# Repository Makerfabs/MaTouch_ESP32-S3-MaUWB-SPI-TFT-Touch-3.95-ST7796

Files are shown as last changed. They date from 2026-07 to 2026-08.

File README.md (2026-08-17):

# MaTouch ESP32-S3 MaUWB SPI TFT Touch 3.95" ST7796

## Introduction

The MaTouch 3.95 MaUWB is an ESP32-S3 development board featuring a 3.95-inch SPI display driven by the ST7796 controller, with a resolution of 480 x 320. It is equipped with an FT6236 capacitive touch controller, 16 MB Flash, and 8 MB PSRAM, providing responsive display and touch interaction for embedded applications.
The board integrates a MaUWB module for UWB ranging and indoor positioning applications. It also supports battery-powered operation, with an onboard lithium battery connector, charging circuit, battery level monitoring, and charge-status indicators, making it suitable for portable positioning terminals.
With its SPI display design, the board retains multiple GPIOs for secondary development through the expansion interface. It also includes a MicroSD card interface, native USB Type-C port, and USB-to-UART Type-C port for programming, debugging, and data storage.
Combining display, capacitive touch, UWB positioning, battery management, and expandable interfaces in one compact platform, the MaTouch 3.95 MaUWB is suitable for education, indoor positioning projects, embedded product development, and rapid prototyping.

Product Link: [MaTouch ESP32-S3 MaUWB SPI TFT Touch 3.95" ST7796](https://www.makerfabs.com/matouch-esp32-s3-mauwb-spi-tft-touch-3-95-st7796.html)

Wiki Link:  [MaTouch ESP32-S3 MaUWB SPI TFT Touch 3.95" ST7796](https://wiki.makerfabs.com/MaTouch%20ESP32_S3%20MaUWB%20SPI%20TFT%20Touch%203.95%27%27%20ST7796.html)

Example：1.[3.95_UWB_position](https://github.com/Makerfabs/MaTouch_ESP32-S3-MaUWB-SPI-TFT-Touch-3.95-ST7796#395_uwb_position)

## Features

- Controller: ESP32-S3 Chipset, 16MB Flash, 8MB PSRAM
- LCD: 3.95", 480X320 resolution 
- LCD Driver: ST7796
- LCD interface: SPI
- Touch Panel: Capacitive
- Touch Driver: FT6336U
- UWB: [MaUWB Chipset](https://www.makerfabs.com/mauwb-dw3000-chipset-ex-antenna-with-sma.html)
- RF band: CH5 (6489.6MHZ) 
- UWB rate: 850K/6.8M
- Max support: 8 Anchor 64 tags
- USB: 1 * USB_native, 1 *USB-to-UART
- USB-UART Driver: CH340K
- Power Supply: USB Type-C 5.0V(4.0V~5.25V)/ Lipo battery 
- Battery Charger
- Expansion interface: 2*JST1.25mm-4P
- LCD Backlight control: Yes

## Example

### 3.95_UWB_position



For details of this example, please refer to the [Wiki](https://wiki.makerfabs.com/MaTouch%20ESP32_S3%20MaUWB%20SPI%20TFT%20Touch%203.95%27%27%20ST7796.html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) document.

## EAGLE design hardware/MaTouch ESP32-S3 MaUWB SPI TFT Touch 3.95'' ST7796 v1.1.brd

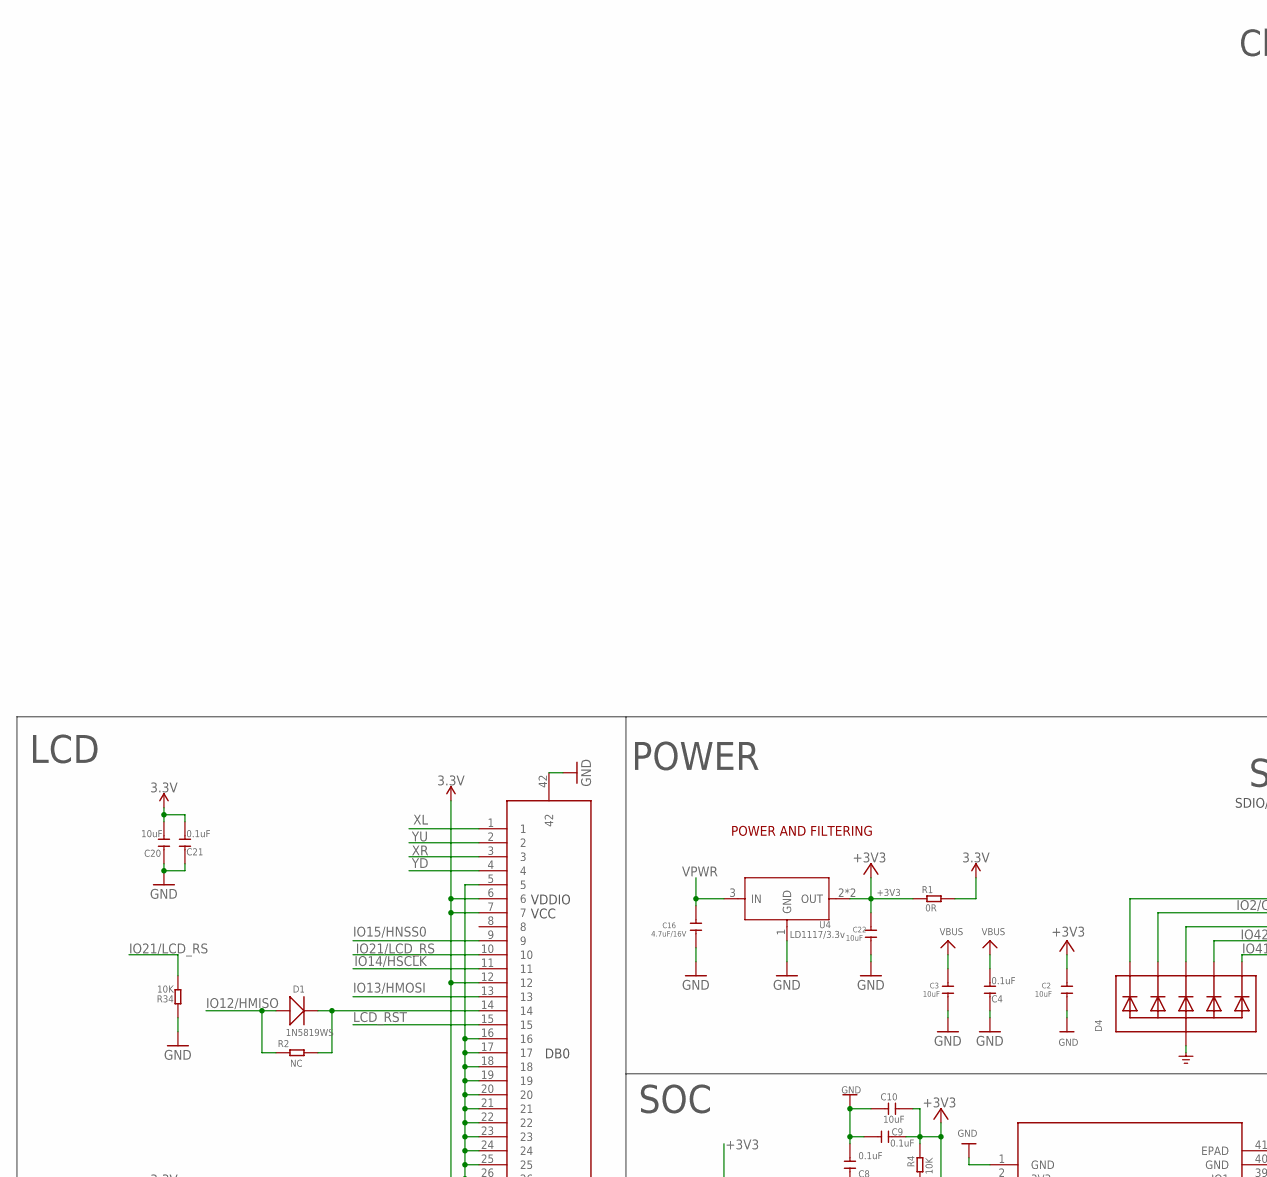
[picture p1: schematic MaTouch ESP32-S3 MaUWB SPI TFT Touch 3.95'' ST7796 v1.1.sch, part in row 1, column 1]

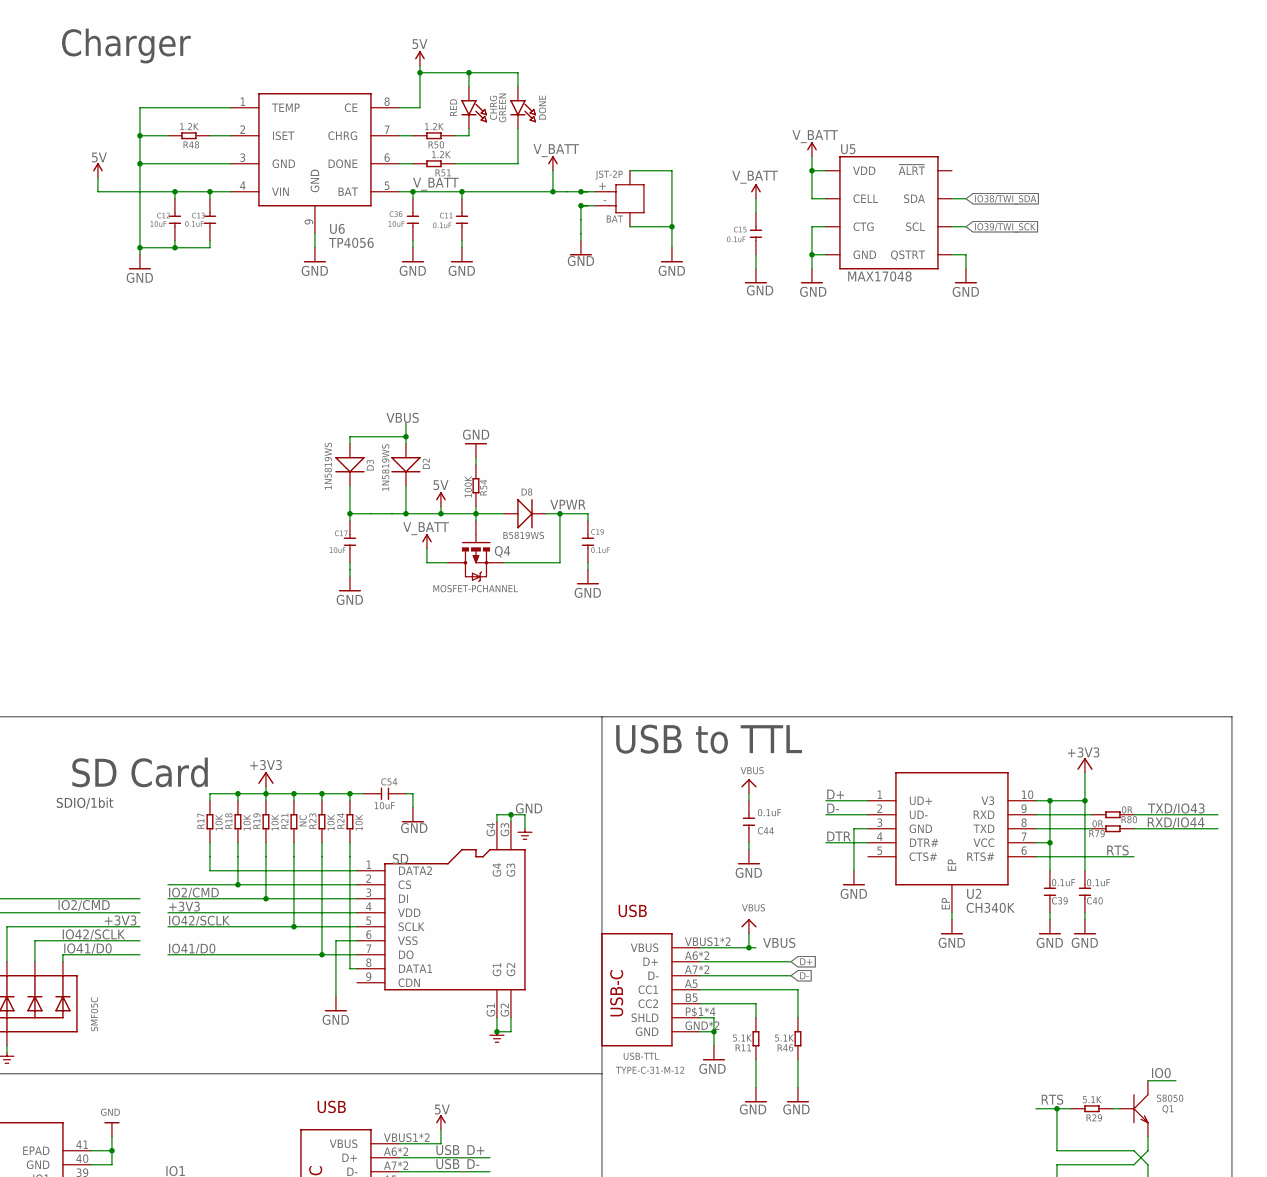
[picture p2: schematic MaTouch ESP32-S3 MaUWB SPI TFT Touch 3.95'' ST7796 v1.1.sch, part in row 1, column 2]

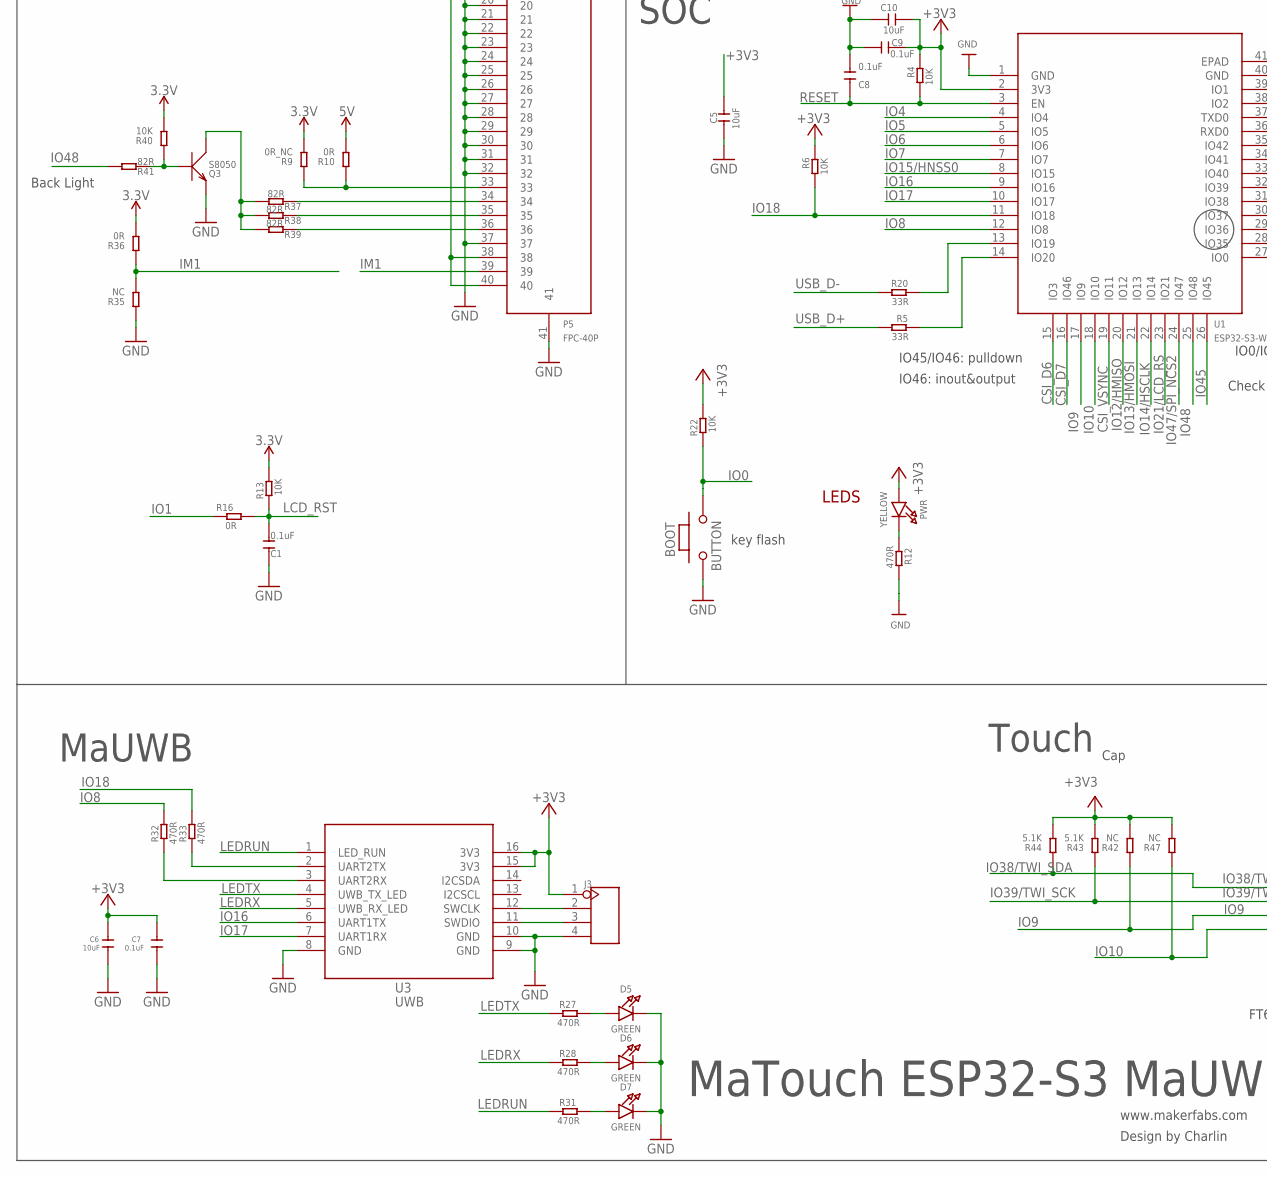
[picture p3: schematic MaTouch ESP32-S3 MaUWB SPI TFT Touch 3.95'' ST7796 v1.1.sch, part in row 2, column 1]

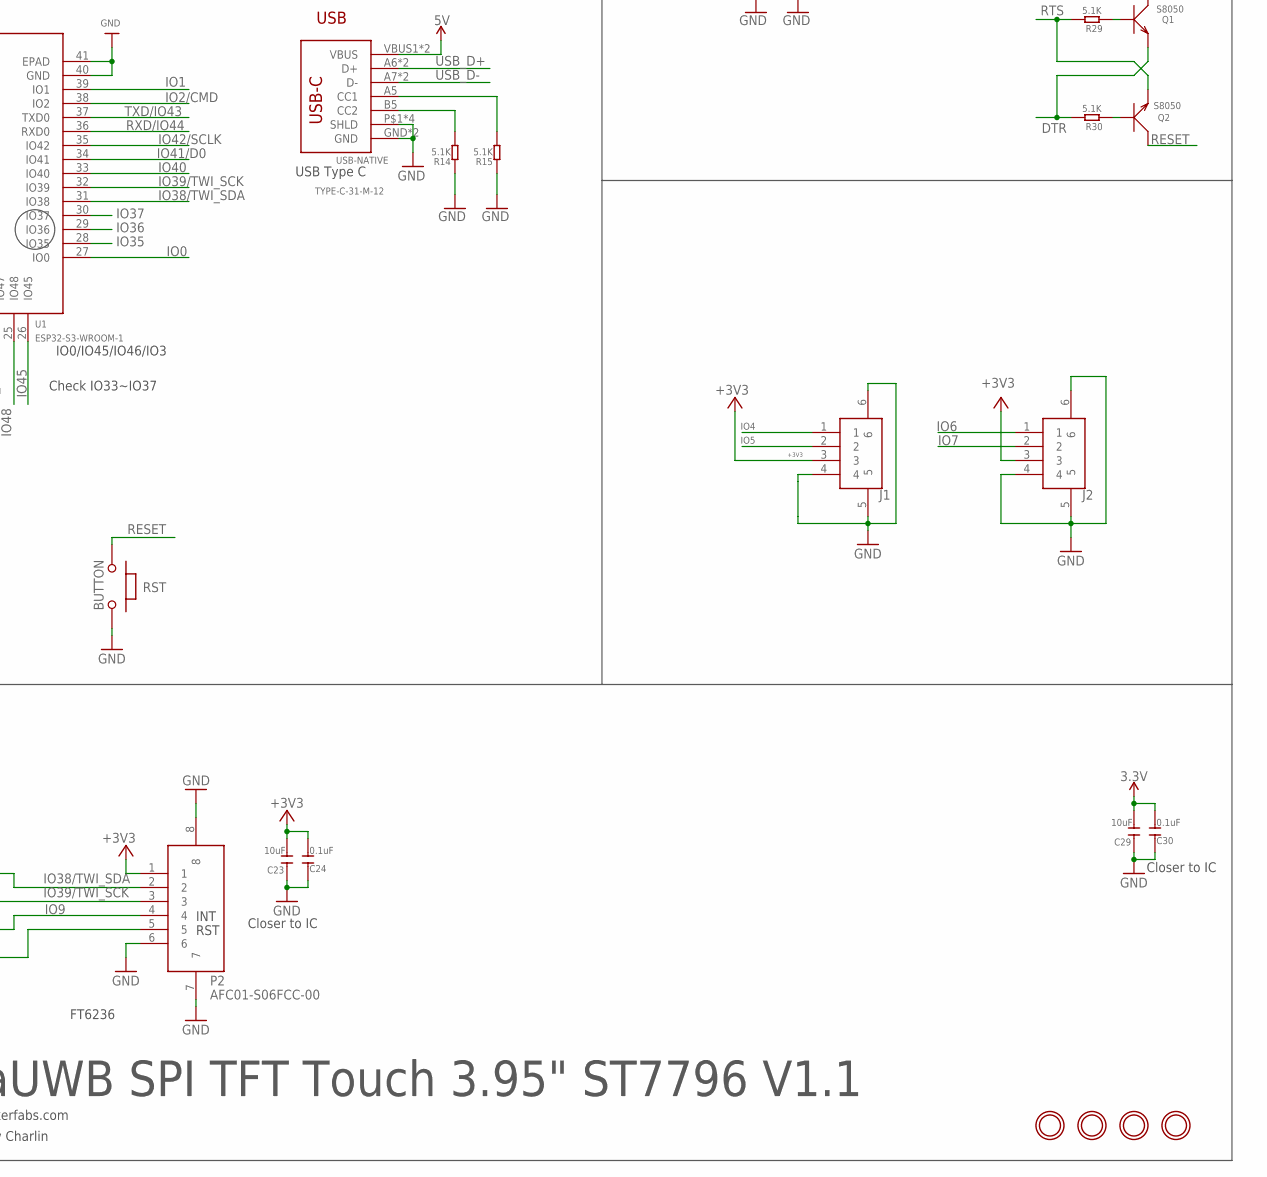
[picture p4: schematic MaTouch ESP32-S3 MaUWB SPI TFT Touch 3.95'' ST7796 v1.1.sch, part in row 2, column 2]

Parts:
BAT: JST-2P; HW2-SMD-2.0-90D
BOOT: BUTTON; 157SW
C1, C4, C8, C9, C21, C24, C30, C39, C40, C44: 0.1uF; DISCRETE_C0603
C2, C3, C6, C12, C17, C22, C36: 10uF; C0603
C5, C10, C20, C23, C29, C54: 10uF; DISCRETE_C0603
C7, C11, C13, C15, C19: 0.1uF; C0603
C16: 4.7uF/16V; C0603
CHRG: RED; CHIPLED_0805_NOOUTLINE
D1, D2, D3: 1N5819WS; SOD323
D4: SMF05C; SOT363
D5, D6, D7: GREEN; CHIPLED_0805_NOOUTLINE
D8: B5819WS; SOD323
DONE: GREEN; CHIPLED_0805_NOOUTLINE
H1, H2, H3, H4: MICROBUILDER_MOUNTINGHOLE3.0THIN; MICROBUILDER_MOUNTINGHOLE_3.0_PLATEDTHIN
J1, J2: CON4-1.25P-SMD; SMD4-125P-1000L525W350H
J3: HEADER-4P-60/35MILROUND; 4P-65/35ROUND
P2: AFC01-S06FCC-00; SMD8-50P-740L535W
P5: FPC-40P; SMD42-50P-2560L490W
PWR: YELLOW; CHIPLED_0805_NOOUTLINE
Q1, Q2, Q3: S8050; SOT23
Q4: MOSFET-PCHANNEL; SOT23-3
R1, R16, R79, R80: 0R; R0603
R2, R21: NC; R0603
R4, R6, R13, R17, R18, R19, R22, R23, R24: 10K; R0603
R5, R20: 33R; R0603
R9: 0R_NC; DISCRETE_R0603
R10, R36: 0R; DISCRETE_R0603
R11, R14, R15, R43, R44, R46: 5.1K; DISCRETE_R0603
R12, R27, R28, R31, R32, R33: 470R; R0603
R29, R30: 5.1K; R0603
R34, R40: 10K; DISCRETE_R0603
R35, R42, R47: NC; DISCRETE_R0603
R37, R38, R39, R41: 82R; DISCRETE_R0603
R48, R50, R51: 1.2K; R0603
R54: 100K; R0603
RST: BUTTON; 157SW
SD: HOLDER-MICROSD-9P; 9P-SMD-W/-RING
U1: ESP32-S3-WROOM-1
U2: CH340K; ESOP-10-EP-150MIL
U3: UWB
U4: LD1117/3.3v; SOT89
U5: MAX17048; DFN-8
U6: TP4056; SOP8-1.27P
USB-NATIVE: TYPE-C-31-M-12
USB-TTL: TYPE-C-31-M-12

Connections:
5V: C12.1, C13.1, C17.1, CHRG.A, D2.-, D3.-, D8.+, DONE.A, Q4.1 (G), R10.2, R54.2, U6.4 (VIN), U6.8 (CE), USB-NATIVE.VBUS1 (VBUS), USB-NATIVE.VBUS2 (VBUS)
+3V3: C2.1, C5.1, C6.1, C7.1, C9.1, C10.1, C20.2, C21.2, C22.1, C23.2, C24.2, C29.2, C30.2, C39.2, C40.2, C54.2, D4.4 (C3), J1.3, J2.3, J3.1, P2.1, P5.6, P5.7, P5.12, P5.38, P5.40, PWR.A, R1.1, R1.2, R4.2, R6.2, R9.2, R13.2, R17.2, R18.2, R19.2, R21.2, R22.2, R23.2, R24.2, R36.2, R40.2, R42.2, R43.2, R44.2, R47.2, SD.4 (VDD), U1.2 (3V3), U2.7 (VCC), U2.10 (V3), U3.15 (3V3), U3.16 (3V3), U4.2 (OUT), U4.4 (OUT)
CSI_D6: U1.15 (IO3)
CSI_D7: U1.16 (IO46)
CSI_VSYNC: U1.19 (IO11)
D+: U2.1 (UD+), USB-TTL.A6 (D+), USB-TTL.B6 (D+)
D-: U2.2 (UD-), USB-TTL.A7 (D-), USB-TTL.B7 (D-)
DTR: Q1.2 (E), R30.2, U2.4 (DTR#)
GND: BAT.3, BAT.4, BAT.- (2), BOOT.1, C1.1, C2.2, C3.2, C4.1, C5.2, C6.2, C7.2, C8.2, C9.2, C10.2, C11.2, C12.2, C13.2, C15.2, C16.2, C17.2, C19.2, C20.1, C21.1, C22.2, C23.1, C24.1, C29.1, C30.1, C36.2, C39.1, C40.1, C44.1, C54.1, D4.2 (A), D5.C, D6.C, D7.C, J1.4, J1.5, J1.6, J2.4, J2.5, J2.6, J3.4, P2.6, P2.7, P2.8, P5.5, P5.16, P5.17, P5.18, P5.19, P5.20, P5.21, P5.22, P5.23, P5.24, P5.25, P5.26, P5.27, P5.28, P5.29, P5.30, P5.31, P5.32, P5.37, P5.41, P5.42, Q3.2 (E), R11.1, R12.2, R14.1, R15.1, R34.1, R35.1, R46.1, R48.2, R54.1, RST.1, SD.6 (VSS), SD.G1, SD.G2, SD.G3, SD.G4, U1.1 (GND), U1.40 (GND), U1.41 (EPAD), U2.3 (GND), U2.EP, U3.8 (GND), U3.9 (GND), U3.10 (GND), U4.1 (GND), U5.1 (CTG), U5.4 (GND), U5.6 (QSTRT), U5.9 (GND), U6.1 (TEMP), U6.3 (GND), U6.9 (GND), USB-NATIVE.GND, USB-NATIVE.GND2 (GND), USB-NATIVE.P$1 (SHLD), USB-NATIVE.P$2 (SHLD), USB-NATIVE.P$3 (SHLD), USB-NATIVE.P$4 (SHLD), USB-TTL.GND, USB-TTL.GND2 (GND), USB-TTL.P$1 (SHLD), USB-TTL.P$2 (SHLD), USB-TTL.P$3 (SHLD), USB-TTL.P$4 (SHLD)
IM1: P5.39, R35.2, R36.1
IO0: BOOT.2, Q1.3 (C), R22.1, U1.27 (IO0)
IO1: R16.1, U1.39 (IO1)
IO1/CS: D4.1 (C1), R18.1, SD.2 (CS)
IO2/CMD: D4.3 (C2), R19.1, SD.3 (DI), U1.38 (IO2)
IO4: J1.1, U1.4 (IO4)
IO5: J1.2, U1.5 (IO5)
IO6: J2.1, U1.6 (IO6)
IO7: J2.2, U1.7 (IO7)
IO8: R32.2, U1.12 (IO8)
IO9: P2.4, R42.1, U1.17 (IO9)
IO10: P2.5, R47.1, U1.18 (IO10)
IO12/HMISO: D1.+, R2.1, U1.20 (IO12)
IO13/HMOSI: P5.13, U1.21 (IO13)
IO14/HSCLK: P5.11, U1.22 (IO14)
IO15/HNSS0: P5.9, U1.8 (IO15)
IO16: U1.9 (IO16), U3.6 (UART1TX)
IO17: U1.10 (IO17), U3.7 (UART1RX)
IO18: R6.1, R33.2, U1.11 (IO18)
IO21/LCD_RS: P5.10, R34.2, U1.23 (IO21)
IO35: U1.28 (IO35)
IO36: U1.29 (IO36)
IO37: U1.30 (IO37)
IO38/TWI_SDA: P2.2, R44.1, U1.31 (IO38), U5.8 (SDA)
IO39/TWI_SCK: P2.3, R43.1, U1.32 (IO39), U5.7 (SCL)
IO40: U1.33 (IO40)
IO41/D0: D4.6 (C5), R23.1, SD.7 (DO), U1.34 (IO41)
IO42/SCLK: D4.5 (C4), R21.1, SD.5 (SCLK), U1.35 (IO42)
IO45: U1.26 (IO45)
IO47/SPI_NCS2: U1.24 (IO47)
IO48: R41.2, U1.25 (IO48)
LCD_RST: C1.2, P5.15, R13.1, R16.2
LEDRUN: R31.1, U3.1 (LED_RUN)
LEDRX: R28.1, U3.5 (UWB_RX_LED)
LEDTX: R27.1, U3.4 (UWB_TX_LED)
unnamed: R46.2, USB-TTL.A5 (CC1)
unnamed: D5.A, R27.2
unnamed: D6.A, R28.2
unnamed: D1.-, P5.14, R2.2
unnamed: Q2.1 (B), R30.1
unnamed: D7.A, R31.2
unnamed: PWR.C, R12.1
unnamed: Q1.1 (B), R29.1
unnamed: R51.2, U6.6 (DONE)
unnamed: R33.1, U3.2 (UART2TX)
unnamed: R32.1, U3.3 (UART2RX)
unnamed: R48.1, U6.2 (ISET)
unnamed: R50.2, U6.7 (CHRG)
unnamed: R15.2, USB-NATIVE.A5 (CC1)
unnamed: R20.2, U1.13 (IO19)
unnamed: R5.2, U1.14 (IO20)
unnamed: R14.2, USB-NATIVE.B5 (CC2)
unnamed: R11.2, USB-TTL.B5 (CC2)
unnamed: CHRG.C, R50.1
unnamed: P5.34, R37.1
unnamed: P5.35, R38.1
unnamed: P5.36, R39.1
unnamed: Q3.1 (B), R40.1, R41.1
unnamed: Q3.3 (C), R37.2, R38.2, R39.2
unnamed: P5.33, R9.1, R10.1
unnamed: J3.3, U3.11 (SWDIO)
unnamed: J3.2, U3.12 (SWCLK)
unnamed: DONE.C, R51.1
unnamed: R80.2, U2.9 (RXD)
unnamed: R79.2, U2.8 (TXD)
unnamed: R17.1, SD.1 (DATA2)
unnamed: R24.1, SD.8 (DATA1)
RESET: C8.1, Q2.3 (C), R4.1, RST.2, U1.3 (EN)
RTS: Q2.2 (E), R29.2, U2.6 (RTS#)
RXD/IO44: R79.1, U1.36 (RXD0)
TXD/IO43: R80.1, U1.37 (TXD0)
USB_D+: R5.1, USB-NATIVE.A6 (D+), USB-NATIVE.B6 (D+)
USB_D-: R20.1, USB-NATIVE.A7 (D-), USB-NATIVE.B7 (D-)
VBUS: C3.1, C4.2, C44.2, D2.+, D3.+, USB-TTL.VBUS1 (VBUS), USB-TTL.VBUS2 (VBUS)
VPWR: C16.1, C19.1, D8.-, Q4.2 (S), U4.3 (IN)
V_BATT: BAT.+ (1), C11.1, C15.1, C36.1, Q4.3 (D), U5.2 (CELL), U5.3 (VDD), U6.5 (BAT)
XL: P5.1
XR: P5.3
YD: P5.4
YU: P5.2

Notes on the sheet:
www.makerfabs.com
Design by Charlin
LEDS
POWER AND FILTERING
key flash
MaTouch ESP32-S3 MaUWB SPI TFT Touch 3.95" ST7796 V1.1
POWER
USB to TTL
SD Card
Closer to IC
Back Light
IO45/IO46: pulldown
IO46: inout&output
USB
USB Type C
IO0/IO45/IO46/IO3
Check IO33~IO37
LCD
SOC
VDDIO
VCC
DB0
SDIO/1bit
MaUWB
FT6236
Touch
RST
INT
Cap
Charger

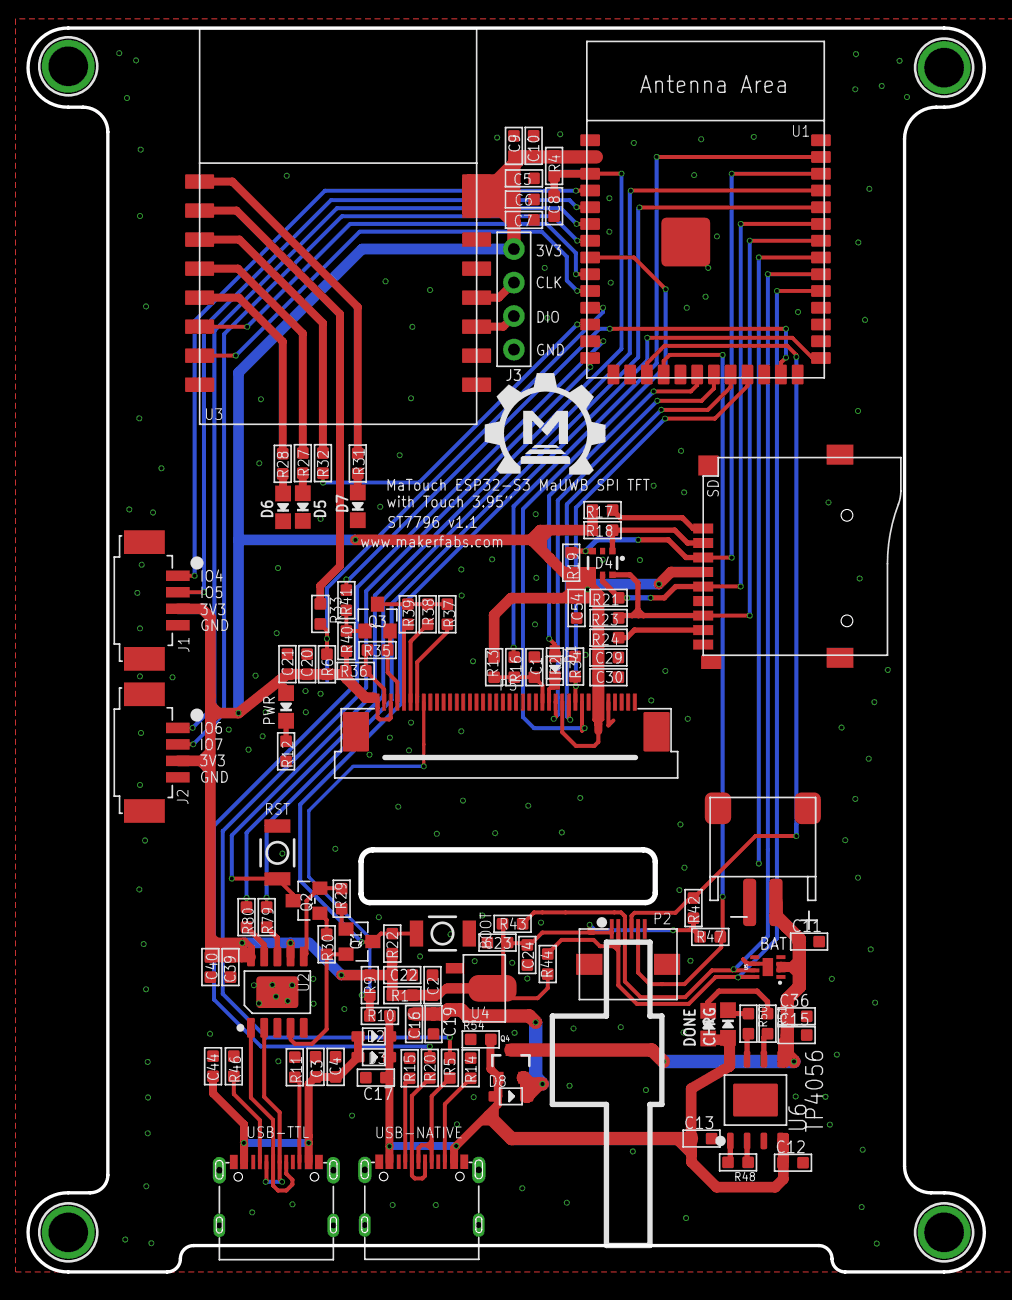
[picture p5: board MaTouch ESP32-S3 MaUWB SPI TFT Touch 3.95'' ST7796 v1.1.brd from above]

Board: 2 copper layers, 72.5 x 94.3 mm, 113 parts (0 on the bottom side), 76 nets.

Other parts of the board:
U$1: MAKERFABS_0.3

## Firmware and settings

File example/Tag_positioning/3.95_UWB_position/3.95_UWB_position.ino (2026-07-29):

/*
esp32 v3.1.0
MaTouch ESP32-S3 3.95 ST7796 + FT6236 + MaUWB AT UART

First positioning demo:
- Three fixed anchors (IDs 0, 1, 2)
- One displayed tag (TARGET_TAG_ID)
- MaUWB AT+RANGE reports are parsed and positioned on the local screen
*/

#include <Arduino_GFX_Library.h>
#include <lvgl.h>
#include <Wire.h>
#include <math.h>
#include <stdlib.h>
#include <string.h>
#include <Preferences.h>
#include "FT6236.h"
#include "MakerfabsLogo.h"

// ==================== Screen parameters ====================
#define SCREEN_WIDTH  320
#define SCREEN_HEIGHT 480

#define GFX_BL    48
#define TFT_SCK   14
#define TFT_MOSI  13
#define TFT_DC    21
#define TFT_CS    15
#define TFT_RST   1

#define TOUCH_SDA 38
#define TOUCH_SCL 39

// ==================== MaUWB parameters ====================
#define UWB_INDEX 0
#define UWB_TAG_COUNT 64
#define UWB_ROLE 0  // 0: Tag, 1: Anchor

#define UWB_RX 16  // ESP32-S3 IO16 <- MaUWB UART1TX
#define UWB_TX 17  // ESP32-S3 IO17 -> MaUWB UART1RX

// Set this to the ID of the tag that should be shown in the first demo.
#define TARGET_TAG_ID 0

#define PRINT_UWB_LINES 1
#define MAX_RANGE_SLOTS 16

HardwareSerial UwbSerial(2);

// ==================== Positioning parameters ====================
struct Anchor {
  int id;
  float x;
  float y;
};

struct TagPosition {
  float x;
  float y;
  bool valid;
};

const int ANCHOR_COUNT = 3;
Anchor anchors[ANCHOR_COUNT] = {
  {0,   0.0f,   0.0f},
  {1, 200.0f,   0.0f},
  {2, 200.0f, 200.0f},
};

float mapMinX = 0.0f;
float mapMaxX = 200.0f;
float mapMinY = 0.0f;
float mapMaxY = 200.0f;
const float FILTER_ALPHA = 0.20f;
const float MOVE_DEADBAND_CM = 5.0f;
const float MAX_MEAN_RESIDUAL_CM = 50.0f;
const uint32_t POSITION_TIMEOUT_MS = 1500;
const uint32_t DISPLAY_INTERVAL_MS = 100;

// ==================== Screen objects ====================
Arduino_DataBus *bus = new Arduino_ESP32SPI(
  TFT_DC,
  TFT_CS,
  TFT_SCK,
  TFT_MOSI,
  GFX_NOT_DEFINED
);

Arduino_GFX *gfx = new Arduino_ST7796(
  bus,
  TFT_RST,
  0,
  false,
  SCREEN_WIDTH,
  SCREEN_HEIGHT
);

// LVGL owns all drawing after the startup logo.  A partial buffer keeps the
// RAM cost low while still allowing the ST7796 to render a polished UI.
static const uint16_t LVGL_DRAW_BUFFER_LINES = 40;
static lv_color_t lvglDrawBuffer[SCREEN_WIDTH * LVGL_DRAW_BUFFER_LINES];
static lv_disp_draw_buf_t lvglDisplayBuffer;
static lv_disp_drv_t lvglDisplayDriver;
static lv_indev_drv_t lvglTouchDriver;
static bool lvglReady = false;

// ==================== Runtime state ====================
char uwbLine[384];
size_t uwbLineLength = 0;

TagPosition tagPosition = {0.0f, 0.0f, false};
float lastRanges[ANCHOR_COUNT] = {0.0f, 0.0f, 0.0f};
bool rangeAvailable[ANCHOR_COUNT] = {false, false, false};
uint32_t lastPositionMs = 0;
uint32_t lastDisplayMs = 0;

enum PositionState {
  STATE_WAITING,
  STATE_VALID,
  STATE_RANGE_ERROR,
  STATE_GEOMETRY_ERROR,
  STATE_OUTSIDE_MAP,
};

PositionState positionState = STATE_WAITING;
Preferences preferences;
char anchorInputs[ANCHOR_COUNT * 2][12] = {""};
char anchorSetupStatus[48] = "Edit anchor coordinates";

// ==================== Display ====================
void showStartupLogo() {
  gfx->fillScreen(WHITE);
  gfx->draw16bitRGBBitmap((SCREEN_WIDTH - MAKERFABS_LOGO_WIDTH) / 2,
                           (SCREEN_HEIGHT - MAKERFABS_LOGO_HEIGHT) / 2,
                           (uint16_t *)makerfabsLogo, MAKERFABS_LOGO_WIDTH,
                           MAKERFABS_LOGO_HEIGHT);
}

const char *positionStateText() {
  if (positionState == STATE_VALID && millis() - lastPositionMs > POSITION_TIMEOUT_MS) {
    return "No UWB data";
  }

  switch (positionState) {
    case STATE_VALID: return "Position valid";
    case STATE_RANGE_ERROR: return "Range error";
    case STATE_GEOMETRY_ERROR: return "Geometry error";
    case STATE_OUTSIDE_MAP: return "Outside map";
    case STATE_WAITING: {
      static char waitingText[32];
      strcpy(waitingText, "Waiting for ");
      bool firstMissing = true;
      for (int i = 0; i < ANCHOR_COUNT; ++i) {
        if (!rangeAvailable[i]) {
          if (!firstMissing) {
            strcat(waitingText, "/");
          }
          char anchorText[4];
          snprintf(anchorText, sizeof(anchorText), "A%d", anchors[i].id);
          strcat(waitingText, anchorText);
          firstMissing = false;
        }
      }
      return firstMissing ? "Waiting for range" : waitingText;
    }
    default: return "Waiting for range";
  }
}

// ==================== Anchor setup screen ====================
void updateMapBounds() {
  float minimumX = anchors[0].x;
  float maximumX = anchors[0].x;
  float minimumY = anchors[0].y;
  float maximumY = anchors[0].y;

  for (int i = 1; i < ANCHOR_COUNT; ++i) {
    minimumX = fminf(minimumX, anchors[i].x);
    maximumX = fmaxf(maximumX, anchors[i].x);
    minimumY = fminf(minimumY, anchors[i].y);
    maximumY = fmaxf(maximumY, anchors[i].y);
  }

  float width = maximumX - minimumX;
  float height = maximumY - minimumY;
  if (width < 80.0f) {
    float center = (minimumX + maximumX) * 0.5f;
    minimumX = center - 40.0f;
    maximumX = center + 40.0f;
    width = 80.0f;
  }
  if (height < 80.0f) {
    float center = (minimumY + maximumY) * 0.5f;
    minimumY = center - 40.0f;
    maximumY = center + 40.0f;
    height = 80.0f;
  }

  float padding = fmaxf(20.0f, fmaxf(width, height) * 0.15f);
  mapMinX = minimumX - padding;
  mapMaxX = maximumX + padding;
  mapMinY = minimumY - padding;
  mapMaxY = maximumY + padding;
}

void syncAnchorInputs() {
  for (int i = 0; i < ANCHOR_COUNT; ++i) {
    snprintf(anchorInputs[i * 2], sizeof(anchorInputs[i * 2]), "%.0f", anchors[i].x);
    snprintf(anchorInputs[i * 2 + 1], sizeof(anchorInputs[i * 2 + 1]), "%.0f", anchors[i].y);
  }
}

bool applyAnchorInputs() {
  float values[ANCHOR_COUNT * 2];
  for (int i = 0; i < ANCHOR_COUNT * 2; ++i) {
    char *end = nullptr;
    values[i] = strtof(anchorInputs[i], &end);
    if (end == anchorInputs[i] || *end != '\0' || !isfinite(values[i]) || fabsf(values[i]) > 100000.0f) {
      int anchorIndex = i / 2;
      snprintf(anchorSetupStatus, sizeof(anchorSetupStatus), "A%d %c is invalid", anchors[anchorIndex].id,
               (i % 2 == 0) ? 'X' : 'Y');
      return false;
    }
  }

  float twiceArea = (values[2] - values[0]) * (values[5] - values[1])
                   - (values[4] - values[0]) * (values[3] - values[1]);
  if (fabsf(twiceArea) < 1.0f) {
    strcpy(anchorSetupStatus, "Anchors cannot be collinear");
    return false;
  }

  for (int i = 0; i < ANCHOR_COUNT; ++i) {
    anchors[i].x = values[i * 2];
    anchors[i].y = values[i * 2 + 1];
  }
  updateMapBounds();
  return true;
}

void saveAnchorConfiguration() {
  preferences.begin("uwbpos", false);
  preferences.putBool("valid", true);
  for (int i = 0; i < ANCHOR_COUNT; ++i) {
    char key[4];
    snprintf(key, sizeof(key), "a%dx", i);
    preferences.putFloat(key, anchors[i].x);
    snprintf(key, sizeof(key), "a%dy", i);
    preferences.putFloat(key, anchors[i].y);
  }
  preferences.end();
}

void loadAnchorConfiguration() {
  preferences.begin("uwbpos", true);
  bool valid = preferences.getBool("valid", false);
  if (valid) {
    for (int i = 0; i < ANCHOR_COUNT; ++i) {
      char key[4];
      snprintf(key, sizeof(key), "a%dx", i);
      anchors[i].x = preferences.getFloat(key, anchors[i].x);
      snprintf(key, sizeof(key), "a%dy", i);
      anchors[i].y = preferences.getFloat(key, anchors[i].y);
    }
    strcpy(anchorSetupStatus, "Saved coordinates loaded");
  }
  preferences.end();
  updateMapBounds();
  syncAnchorInputs();
}

// ==================== Positioning ====================
int findAnchorIndex(int id) {
  for (int i = 0; i < ANCHOR_COUNT; ++i) {
    if (anchors[i].id == id) {
      return i;
    }
  }
  return -1;
}

bool calculatePosition(const float ranges[ANCHOR_COUNT], float &x, float &y) {
  const Anchor &reference = anchors[0];
  const Anchor &anchor1 = anchors[1];
  const Anchor &anchor2 = anchors[2];

  float a11 = 2.0f * (anchor1.x - reference.x);
  float a12 = 2.0f * (anchor1.y - reference.y);
  float a21 = 2.0f * (anchor2.x - reference.x);
  float a22 = 2.0f * (anchor2.y - reference.y);

  float b1 = ranges[0] * ranges[0] - ranges[1] * ranges[1]
             + anchor1.x * anchor1.x - reference.x * reference.x
             + anchor1.y * anchor1.y - reference.y * reference.y;
  float b2 = ranges[0] * ranges[0] - ranges[2] * ranges[2]
             + anchor2.x * anchor2.x - reference.x * reference.x
             + anchor2.y * anchor2.y - reference.y * reference.y;

  float determinant = a11 * a22 - a12 * a21;
  if (fabsf(determinant) < 0.001f) {
    return false;
  }

  x = (b1 * a22 - a12 * b2) / determinant;
  y = (a11 * b2 - b1 * a21) / determinant;
  return isfinite(x) && isfinite(y);
}

bool positionHasAcceptableResidual(float x, float y, const float ranges[ANCHOR_COUNT]) {
  float totalResidual = 0.0f;
  for (int i = 0; i < ANCHOR_COUNT; ++i) {
    float dx = x - anchors[i].x;
    float dy = y - anchors[i].y;
    float calculatedRange = sqrtf(dx * dx + dy * dy);
    totalResidual += fabsf(calculatedRange - ranges[i]);
  }
  return totalResidual / ANCHOR_COUNT <= MAX_MEAN_RESIDUAL_CM;
}

void updateTagPosition(float rawX, float rawY) {
  if (!tagPosition.valid) {
    tagPosition.x = rawX;
    tagPosition.y = rawY;
    tagPosition.valid = true;
  } else {
    float filteredX = tagPosition.x * (1.0f - FILTER_ALPHA) + rawX * FILTER_ALPHA;
    float filteredY = tagPosition.y * (1.0f - FILTER_ALPHA) + rawY * FILTER_ALPHA;
    float dx = filteredX - tagPosition.x;
    float dy = filteredY - tagPosition.y;

    if (sqrtf(dx * dx + dy * dy) >= MOVE_DEADBAND_CM) {
      tagPosition.x = filteredX;
      tagPosition.y = filteredY;
    }
  }

  lastPositionMs = millis();
  positionState = STATE_VALID;
}

// ==================== MaUWB report parsing ====================
bool parseIntegerAfter(const char *text, const char *key, int &value) {
  const char *start = strstr(text, key);
  if (start == nullptr) {
    return false;
  }

  start += strlen(key);
  char *end = nullptr;
  long parsed = strtol(start, &end, 10);
  if (end == start) {
    return false;
  }

  value = (int)parsed;
  return true;
}

int parseNumberList(const char *text, int values[], int capacity) {
  int count = 0;
  const char *cursor = text;

  while (*cursor != '\0' && *cursor != ')') {
    while (*cursor == ' ' || *cursor == '\t') {
      ++cursor;
    }

    if (count >= capacity) {
      return -1;
    }

    char *end = nullptr;
    long parsed = strtol(cursor, &end, 10);
    if (end == cursor) {
      return -1;
    }
    values[count++] = (int)parsed;
    cursor = end;

    while (*cursor == ' ' || *cursor == '\t') {
      ++cursor;
    }
    if (*cursor == ',') {
      ++cursor;
    } else if (*cursor != ')') {
      return -1;
    }
  }

  return (*cursor == ')') ? count : -1;
}

void processRangeReport(const char *line) {
  int tagId = -1;
  if (!parseIntegerAfter(line, "tid:", tagId) || tagId != TARGET_TAG_ID) {
    return;
  }

  const char *rangeList = strstr(line, "range:(");
  const char *anchorList = strstr(line, "ancid:(");
  if (rangeList == nullptr || anchorList == nullptr) {
    positionState = STATE_RANGE_ERROR;
    return;
  }

  int rawRanges[MAX_RANGE_SLOTS];
  int rawAnchorIds[MAX_RANGE_SLOTS];
  int rangeCount = parseNumberList(rangeList + 7, rawRanges, MAX_RANGE_SLOTS);
  int anchorCount = parseNumberList(anchorList + 7, rawAnchorIds, MAX_RANGE_SLOTS);
  if (rangeCount <= 0 || rangeCount != anchorCount) {
    positionState = STATE_RANGE_ERROR;
    return;
  }

  float pairedRanges[ANCHOR_COUNT] = {0.0f, 0.0f, 0.0f};
  bool found[ANCHOR_COUNT] = {false, false, false};

  // Keep each ancid[i] paired with its original range[i].
  for (int i = 0; i < rangeCount; ++i) {
    int anchorIndex = findAnchorIndex(rawAnchorIds[i]);
    if (anchorIndex >= 0 && rawRanges[i] > 0) {
      pairedRanges[anchorIndex] = (float)rawRanges[i];
      found[anchorIndex] = true;
    }
  }

  // Update the distance display for every valid anchor in this report.
  for (int i = 0; i < ANCHOR_COUNT; ++i) {
    rangeAvailable[i] = found[i];
    if (found[i]) {
      lastRanges[i] = pairedRanges[i];
    }
  }

  for (int i = 0; i < ANCHOR_COUNT; ++i) {
    if (!found[i]) {
      positionState = STATE_WAITING;
      return;
    }
  }

  float rawX;
  float rawY;
  if (!calculatePosition(pairedRanges, rawX, rawY)) {
    positionState = STATE_GEOMETRY_ERROR;
    return;
  }

  if (!positionHasAcceptableResidual(rawX, rawY, pairedRanges)) {
    positionState = STATE_RANGE_ERROR;
    return;
  }

  if (rawX < mapMinX - 30.0f || rawX > mapMaxX + 30.0f ||
      rawY < mapMinY - 30.0f || rawY > mapMaxY + 30.0f) {
    positionState = STATE_OUTSIDE_MAP;
    return;
  }

  updateTagPosition(rawX, rawY);

  Serial.printf("T%d -> X:%.1f cm, Y:%.1f cm | A0:%.0f A1:%.0f A2:%.0f\n",
                tagId, rawX, rawY,
                pairedRanges[0], pairedRanges[1], pairedRanges[2]);
}

void processUwbLine(const char *line) {
  if (PRINT_UWB_LINES) {
    Serial.println(line);
  }

  if (strncmp(line, "AT+RANGE=", 9) == 0) {
    processRangeReport(line);
  }
}

// ==================== MaUWB setup and serial ====================
String uwbConfigCommand() {
  String command = "AT+SETCFG=";
  command += UWB_INDEX;
  command += ",";
  command += UWB_ROLE;
  command += ",1";  // 1: 6.8M, 0: 850K
  command += ",1";  // Range filter on
  return command;
}

String uwbCapacityCommand() {
  String command = "AT+SETCAP=";
  command += UWB_TAG_COUNT;
  command += ",10"; // 6.8M slot time: 10 ms
  command += ",1";  // Extended packet mode
  return command;
}

String sendUwbCommand(const String &command, uint32_t timeoutMs, bool debug) {
  String response = "";

  Serial.println(command);
  UwbSerial.println(command);

  uint32_t start = millis();
  while (millis() - start < timeoutMs) {
    while (UwbSerial.available()) {
      response += (char)UwbSerial.read();
    }
  }

  if (debug) {
    Serial.println(response);
  }

  return response;
}

void initUwb() {
  UwbSerial.begin(115200, SERIAL_8N1, UWB_RX, UWB_TX);
  delay(300);

  sendUwbCommand("AT?", 2000, true);
  sendUwbCommand("AT+RESTORE", 5000, true);
  sendUwbCommand(uwbConfigCommand(), 2000, true);
  sendUwbCommand(uwbCapacityCommand(), 2000, true);
  sendUwbCommand("AT+SETRPT=1", 2000, true);
  sendUwbCommand("AT+SAVE", 2000, true);
  sendUwbCommand("AT+RESTART", 2000, true);
}

void handleUwbSerial() {
  // Keep the USB serial bridge for manual MaUWB AT commands.
  while (Serial.available() > 0) {
    UwbSerial.write(Serial.read());
  }

  while (UwbSerial.available() > 0) {
    char c = (char)UwbSerial.read();

    if (c == '\r') {
      continue;
    }

    if (c == '\n') {
      if (uwbLineLength > 0) {
        uwbLine[uwbLineLength] = '\0';
        processUwbLine(uwbLine);
        uwbLineLength = 0;
      }
    } else if (uwbLineLength < sizeof(uwbLine) - 1) {
      uwbLine[uwbLineLength++] = c;
    } else {
      // Drop an overlong line rather than corrupting the parser buffer.
      uwbLineLength = 0;
      positionState = STATE_RANGE_ERROR;
      Serial.println("UWB line too long; dropped");
    }
  }
}

// ==================== LVGL user interface ====================
const int LVGL_MAP_X = 14;
const int LVGL_MAP_Y = 98;
const int LVGL_MAP_W = 292;
const int LVGL_MAP_H = 232;
const int LVGL_MAP_MARGIN = 18;

const uint32_t UI_BG = 0x10191D;
const uint32_t UI_SURFACE = 0x1B292F;
const uint32_t UI_SURFACE_ALT = 0x243840;
const uint32_t UI_TEAL = 0x14A6A2;
const uint32_t UI_TEAL_DARK = 0x0B565B;
const uint32_t UI_TEXT = 0xF4FAFA;
const uint32_t UI_MUTED = 0x9AB1B6;
const uint32_t UI_GRID = 0x42646A;
const uint32_t UI_TAG = 0xFF6B5E;
const uint32_t UI_OK = 0x35C486;
const uint32_t UI_WARN = 0xF3B85B;
const uint32_t UI_ERROR = 0xEE625C;

lv_obj_t *positionScreen = nullptr;
lv_obj_t *setupScreen = nullptr;
lv_obj_t *lvglMap = nullptr;
lv_obj_t *coordinateLabel = nullptr;
lv_obj_t *statusLabel = nullptr;
lv_obj_t *rangeValueLabels[ANCHOR_COUNT] = {nullptr, nullptr, nullptr};
lv_obj_t *anchorDots[ANCHOR_COUNT] = {nullptr, nullptr, nullptr};
lv_obj_t *anchorTextLabels[ANCHOR_COUNT] = {nullptr, nullptr, nullptr};
lv_obj_t *rangeLines[ANCHOR_COUNT] = {nullptr, nullptr, nullptr};
lv_point_t rangeLinePoints[ANCHOR_COUNT][2];
lv_point_t mapGridVertical[3][2];
lv_point_t mapGridHorizontal[3][2];
lv_obj_t *tagDot = nullptr;
lv_obj_t *tagLabel = nullptr;
lv_obj_t *setupValueLabels[ANCHOR_COUNT * 2] = {nullptr, nullptr, nullptr, nullptr, nullptr, nullptr};
lv_obj_t *setupStatusLabel = nullptr;
lv_obj_t *editOverlay = nullptr;
lv_obj_t *editInput = nullptr;
lv_obj_t *editHintLabel = nullptr;
int editingAnchorInput = -1;

lv_color_t uiColor(uint32_t color) {
  return lv_color_hex(color);
}

void styleSurface(lv_obj_t *object, uint32_t color, uint8_t radius) {
  lv_obj_set_style_bg_color(object, uiColor(color), 0);
  lv_obj_set_style_bg_opa(object, LV_OPA_COVER, 0);
  lv_obj_set_style_radius(object, radius, 0);
  lv_obj_set_style_border_width(object, 0, 0);
  lv_obj_set_style_pad_all(object, 0, 0);
}

lv_obj_t *createLabel(lv_obj_t *parent, const char *text, uint32_t color) {
  lv_obj_t *label = lv_label_create(parent);
  lv_label_set_text(label, text);
  lv_obj_set_style_text_color(label, uiColor(color), 0);
  return label;
}

lv_obj_t *createButton(lv_obj_t *parent, int x, int y, int width, int height,
                       const char *text, uint32_t color, lv_event_cb_t callback,
                       void *userData = nullptr) {
  lv_obj_t *button = lv_btn_create(parent);
  lv_obj_set_pos(button, x, y);
  lv_obj_set_size(button, width, height);
  styleSurface(button, color, 7);
  lv_obj_set_style_bg_color(button, uiColor(UI_TEAL), LV_PART_MAIN | LV_STATE_PRESSED);
  lv_obj_set_style_text_color(button, uiColor(UI_TEXT), 0);
  lv_obj_add_event_cb(button, callback, LV_EVENT_CLICKED, userData);
  if (text != nullptr && text[0] != '\0') {
    lv_obj_t *label = createLabel(button, text, UI_TEXT);
    lv_obj_center(label);
  }
  return button;
}

void lvglFlush(lv_disp_drv_t *display, const lv_area_t *area, lv_color_t *colors) {
  int width = area->x2 - area->x1 + 1;
  int height = area->y2 - area->y1 + 1;
  gfx->draw16bitRGBBitmap(area->x1, area->y1, (uint16_t *)colors, width, height);
  lv_disp_flush_ready(display);
}

void lvglTouchRead(lv_indev_drv_t *input, lv_indev_data_t *data) {
  (void)input;
  int position[2];
  if (ft6236_pos(position)) {
    data->point.x = constrain(position[0], 0, SCREEN_WIDTH - 1);
    data->point.y = constrain(position[1], 0, SCREEN_HEIGHT - 1);
    data->state = LV_INDEV_STATE_PRESSED;
  } else {
    data->state = LV_INDEV_STATE_RELEASED;
  }
}

float lvglMapScale() {
  float scaleX = (LVGL_MAP_W - 2 * LVGL_MAP_MARGIN) / (mapMaxX - mapMinX);
  float scaleY = (LVGL_MAP_H - 2 * LVGL_MAP_MARGIN) / (mapMaxY - mapMinY);
  return (scaleX < scaleY) ? scaleX : scaleY;
}

int worldToLvglMapX(float x) {
  float plotWidth = (mapMaxX - mapMinX) * lvglMapScale();
  int contentWidth = LVGL_MAP_W - 2 * LVGL_MAP_MARGIN;
  return LVGL_MAP_MARGIN + (contentWidth - (int)plotWidth) / 2
         + (int)lroundf((x - mapMinX) * lvglMapScale());
}

int worldToLvglMapY(float y) {
  float plotHeight = (mapMaxY - mapMinY) * lvglMapScale();
  int contentHeight = LVGL_MAP_H - 2 * LVGL_MAP_MARGIN;
  return LVGL_MAP_MARGIN + (contentHeight - (int)plotHeight) / 2
         + (int)lroundf((mapMaxY - y) * lvglMapScale());
}

void updateSetupValueLabels() {
  if (setupStatusLabel == nullptr) {
    return;
  }
  for (int i = 0; i < ANCHOR_COUNT * 2; ++i) {
    if (setupValueLabels[i] != nullptr) {
      lv_label_set_text(setupValueLabels[i], anchorInputs[i]);
    }
  }
  lv_label_set_text(setupStatusLabel, anchorSetupStatus);
}

void updateLvglMap() {
  if (lvglMap == nullptr) {
    return;
  }

  for (int i = 0; i < ANCHOR_COUNT; ++i) {
    int anchorX = worldToLvglMapX(anchors[i].x);
    int anchorY = worldToLvglMapY(anchors[i].y);
    lv_obj_set_pos(anchorDots[i], anchorX - 5, anchorY - 5);
    lv_obj_set_pos(anchorTextLabels[i], constrain(anchorX + 8, 2, LVGL_MAP_W - 26),
                   constrain(anchorY - 17, 2, LVGL_MAP_H - 18));
  }

  int tagX = 0;
  int tagY = 0;
  bool hasPosition = tagPosition.valid && positionState == STATE_VALID &&
                     millis() - lastPositionMs <= POSITION_TIMEOUT_MS;
  if (hasPosition) {
    tagX = constrain(worldToLvglMapX(tagPosition.x), LVGL_MAP_MARGIN, LVGL_MAP_W - LVGL_MAP_MARGIN);
    tagY = constrain(worldToLvglMapY(tagPosition.y), LVGL_MAP_MARGIN, LVGL_MAP_H - LVGL_MAP_MARGIN);
    lv_obj_clear_flag(tagDot, LV_OBJ_FLAG_HIDDEN);
    lv_obj_clear_flag(tagLabel, LV_OBJ_FLAG_HIDDEN);
    lv_obj_set_pos(tagDot, tagX - 7, tagY - 7);
    lv_obj_set_pos(tagLabel, constrain(tagX + 10, 2, LVGL_MAP_W - 88),
                   constrain(tagY + 7, 2, LVGL_MAP_H - 18));
    lv_label_set_text_fmt(tagLabel, "T%d (%d, %d)", TARGET_TAG_ID,
                          (int)lroundf(tagPosition.x), (int)lroundf(tagPosition.y));
  } else {
    lv_obj_add_flag(tagDot, LV_OBJ_FLAG_HIDDEN);
    lv_obj_add_flag(tagLabel, LV_OBJ_FLAG_HIDDEN);
  }

  for (int i = 0; i < ANCHOR_COUNT; ++i) {
    if (hasPosition && rangeAvailable[i]) {
      rangeLinePoints[i][0].x = worldToLvglMapX(anchors[i].x);
      rangeLinePoints[i][0].y = worldToLvglMapY(anchors[i].y);
      rangeLinePoints[i][1].x = tagX;
      rangeLinePoints[i][1].y = tagY;
      lv_line_set_points(rangeLines[i], rangeLinePoints[i], 2);
      lv_obj_clear_flag(rangeLines[i], LV_OBJ_FLAG_HIDDEN);
    } else {
      lv_obj_add_flag(rangeLines[i], LV_OBJ_FLAG_HIDDEN);
    }
  }
}
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
void loop() {
  handleUwbSerial();

  // Touch is polled by LVGL through lvglTouchRead().
  lv_timer_handler();

  if (millis() - lastDisplayMs >= DISPLAY_INTERVAL_MS) {
    lastDisplayMs = millis();
    refreshLvglPositionPage();
  }
}

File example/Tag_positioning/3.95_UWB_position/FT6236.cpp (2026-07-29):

#include "FT6236.h"

int readTouchReg(int reg)
{
    int data = 0;
    Wire.beginTransmission(TOUCH_I2C_ADD);
    Wire.write(reg);
    Wire.endTransmission();
    Wire.requestFrom(TOUCH_I2C_ADD, 1);
    if (Wire.available())
    {
        data = Wire.read();
    }
    return data;
}

/*
int getTouchPointX()
{
    int XL = 0;
    int XH = 0;

    XH = readTouchReg(TOUCH_REG_XH);
    XL = readTouchReg(TOUCH_REG_XL);

    return ((XH & 0x0F) << 8) | XL;
}
*/

int getTouchPointX()
{
    int XL = 0;
    int XH = 0;

    XH = readTouchReg(TOUCH_REG_XH);
    //Serial.println(XH >> 6,HEX);
    if(XH >> 6 == 1)
        return -1;
    XL = readTouchReg(TOUCH_REG_XL);

    return ((XH & 0x0F) << 8) | XL;
}

int getTouchPointY()
{
    int YL = 0;
    int YH = 0;

    YH = readTouchReg(TOUCH_REG_YH);
    YL = readTouchReg(TOUCH_REG_YL);

    return ((YH & 0x0F) << 8) | YL;
}

int ft6236_pos(int pos[2])
{
    int XL = 0;
    int XH = 0;
    int YL = 0;
    int YH = 0;

    if ((readTouchReg(TOUCH_REG_TD_STATUS) & 0x0F) == 0)
    {
        pos[0] = -1;
        pos[1] = -1;
        return 0;
    }

    XH = readTouchReg(TOUCH_REG_XH);
    XL = readTouchReg(TOUCH_REG_XL);
    YH = readTouchReg(TOUCH_REG_YH);
    YL = readTouchReg(TOUCH_REG_YL);

    pos[0] = ((XH & 0x0F) << 8) | XL;
    pos[1] = ((YH & 0x0F) << 8) | YL;
    return 1;
}

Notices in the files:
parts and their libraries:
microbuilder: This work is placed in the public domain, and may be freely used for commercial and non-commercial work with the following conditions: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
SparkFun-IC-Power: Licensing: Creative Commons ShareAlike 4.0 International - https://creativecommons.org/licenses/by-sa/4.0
